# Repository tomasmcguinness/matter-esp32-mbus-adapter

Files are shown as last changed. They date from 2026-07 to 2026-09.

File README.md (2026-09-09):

# Matter ESP32 M-Bus Adapter

> ⚠️ **Work in progress.** This project is under active development and is not
> finished. The hardware is at the bring-up stage, the firmware currently runs in
> a bench-test mode that logs meter data rather than publishing it over Matter,
> and nothing here should be considered stable or production-ready. Expect
> breaking changes, incomplete features and rough edges.

A [Matter](https://csa-iot.org/all-solutions/matter/) accessory that reads a
wired [M-Bus](https://en.wikipedia.org/wiki/Meter-Bus) (EN 13757) heat meter and
exposes its readings — flow rate, flow/return temperatures and power — to a
Matter fabric over Thread.

It is built around an **ESP32-C6** (native 802.15.4 radio) and a custom PCB that
provides the M-Bus master side: the ~36 V/~24 V bus supply, the mark/space
modulator and the receive comparator, so a meter can be connected directly to the
board's M+/M- terminals.

## Repository layout

| Path | Contents |
|---|---|
| `firmware/` | The main ESP-IDF / esp-matter application for the ESP32-C6 |
| `hardware/PCB/` | KiCad schematic, PCB layout and BOM (`PCB.csv`, Mouser part numbers) |
| `tools/pcb-test/` | Standalone GPIO-only app for bringing up the M-Bus analogue circuit — see its own [README](tools/pcb-test/README.md) |

## Firmware

Source lives in `firmware/main`:

- `mbus.cpp` / `mbus.h` — the M-Bus link layer: UART setup (2400 8E1), `SND_NKE`
  link reset and `REQ_UD2` data requests, frame validation and checksums.
- `mbus_parser.cpp` / `mbus_parser.h` — decodes EN 13757-3 data records into a
  `heat_meter_data_t` struct, plus a verbose `mbus_parse_test()` used on the bench.
- `heat_meter_cluster.h` — IDs for a manufacturer-specific *Heat Meter* cluster,
  which carries the meter dataset at higher precision than the standard Flow
  Measurement cluster allows.
- `main.cpp` — brings up the Matter node and endpoints and runs the M-Bus poll task.

### Bring-up modes

`main.cpp` has an `MBUS_MODE` switch so each layer can be proven in turn. It
currently defaults to `MBUS_MODE_TEST`.

| Mode | Behaviour |
|---|---|
| `MBUS_MODE_NKE_ONLY` | Sends `SND_NKE` on a loop and reports whether the meter ACKs — checks wiring and polarity only |
| `MBUS_MODE_TEST` | Requests data and hex-dumps/decodes every record found. Nothing reaches Matter |
| `MBUS_MODE_NORMAL` | Parses into `heat_meter_data_t` and publishes to the Matter data model |

### Building

Requires ESP-IDF (with `esp_matter` pulled in as a managed component — see
`firmware/main/idf_component.yml`).

The radio is chosen by an explicit defaults overlay, so there is no single
`idf.py build` — each variant gets its own build directory and generated config,
and the two never collide. `set-target` is needed once per build directory.

```sh
cd firmware

# Thread — the supported configuration
idf.py -B build.thread -DSDKCONFIG=sdkconfig.thread \
  -DSDKCONFIG_DEFAULTS="sdkconfig.defaults;sdkconfig.defaults.thread" \
  set-target esp32c6
idf.py -B build.thread -DSDKCONFIG=sdkconfig.thread \
  -DSDKCONFIG_DEFAULTS="sdkconfig.defaults;sdkconfig.defaults.thread" \
  build flash monitor

# Wi-Fi — read the warning in sdkconfig.defaults.wifi first
idf.py -B build.wifi -DSDKCONFIG=sdkconfig.wifi \
  -DSDKCONFIG_DEFAULTS="sdkconfig.defaults;sdkconfig.defaults.wifi" \
  set-target esp32c6
idf.py -B build.wifi -DSDKCONFIG=sdkconfig.wifi \
  -DSDKCONFIG_DEFAULTS="sdkconfig.defaults;sdkconfig.defaults.wifi" \
  build flash monitor
```

`SDKCONFIG_DEFAULTS` must be passed to **`set-target` as well as `build`**.
`set-target` is what creates the config file, and defaults are only ever applied
when the file is created — pass it only to `build` and you silently get a config
with no radio overlay at all.

`sdkconfig.defaults.esp32c6` holds the settings common to both and selects no
radio. IDF appends `<file>.esp32c6` to every entry in `SDKCONFIG_DEFAULTS`, so it
is applied automatically and only the radio overlay has to be named.

Note that editing a defaults file does **not** update an existing generated
config — IDF only seeds one that does not yet exist. That is why each variant has
its own `-DSDKCONFIG`; if you do need to re-seed one, delete it first.

BLE is used for commissioning in both cases.

**Wi-Fi does not work on revision F hardware.** The 3V3 LDO (U3, `MCP1700T-3302E/TT`)
supplies 250 mA against a Wi-Fi TX peak north of 300 mA, so the board
brownout-resets at association and never finishes starting. Thread's 802.15.4 TX
peak fits the budget. See `firmware/sdkconfig.defaults.wifi` for the full
measurements and what a hardware fix would need.

### Factory reset

**SW2** is the ESP32-C6 BOOT button (net `BOOT` → IO9). Hold it for **five
seconds while the device is running** to wipe the Matter credentials from NVS and
reboot uncommissioned. The status LED (D3, net `LED` → IO15) blinks faster as the
hold progresses and goes solid at the moment the reset commits, so the button can
be released once it stops flashing.

Release before five seconds and nothing happens — the aborted hold is logged with
its elapsed time.

IO9 is a strapping pin, so holding SW2 *across* a power-up or an SW1 press puts
the chip into serial-download mode and the application never starts. That is
useful for flashing, but it is **not** the factory-reset gesture — the device has
to already be running.

SW1 pulls `EN` low and is a plain hardware reset; it does not touch NVS.

## Known limitations

- Matter publishing is commented out in `main.cpp` while bench testing continues.
- The LDO (U3, `MCP1700`, 250 mA) cannot supply Wi-Fi. Confirmed on the bench:
  10 brownout resets in 15 s, every one at Wi-Fi association. Thread works; Wi-Fi
  needs more bulk capacitance on 3V3 and/or a 500-600 mA regulator.
- The custom cluster uses the Matter **test** vendor ID `0xFFF1`. A real product
  would need an allocated Vendor ID.
- Raw RX hex logging is enabled in `mbus.cpp` (`MBUS_LOG_RAW_RX`) and should be
  turned off for production.
- Only a subset of M-Bus data records is decoded, and it has so far been
  exercised against a test slave rather than a wide range of real meters.

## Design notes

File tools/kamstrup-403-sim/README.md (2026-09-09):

# Kamstrup MULTICAL 403 M-Bus slave simulator

An Arduino sketch that makes a Raspberry Pi Pico answer M-Bus polls the way a
Kamstrup MULTICAL 403 heat meter does, so the ESP32-C6 adapter in `firmware/`
can be exercised without the real meter on the desk.

Unlike the generic bench slave that `mbus_parse_test()` was written for, this
emits a telegram a real 403 would send — Kamstrup identity fields, CI `0x72`
with a proper 12-byte header, and standard EN 13757-3 data records — so it
exercises the **production** decode path, `mbus_parse()`.

Modelled on [HWHardsoft/Arduino-MBUS-Meter](https://github.com/HWHardsoft/Arduino-MBUS-Meter)
(GPLv3, via OpenEnergyMonitor's HeatpumpMonitor), retargeted from its AEG
electricity-meter payload to a heat meter.

## Build

Either RP2040 core works:

- **Arduino Mbed OS RP2040 Boards** — in Boards Manager by default. Serial1's
  pins are fixed at construction, but they are already GP0/GP1.
- **[arduino-pico](https://github.com/earlephilhower/arduino-pico)**
  (earlephilhower) — add the Boards Manager URL
  `https://github.com/earlephilhower/arduino-pico/releases/download/global/package_rp2040_index.json`.
  Lets the sketch move the UART with `setTX`/`setRX`, so `MBUS_TX_PIN` /
  `MBUS_RX_PIN` in `mbusslave.h` can be changed.

The sketch detects which core it is on (`ARDUINO_ARCH_MBED`) and skips the pin
assignment where it is not supported — see `MBUS_SERIAL_PINS_FIXED` in
`mbusslave.h`. The startup banner prints which pins are actually in use. Both
cores honour `SERIAL_8E1`, which is the part M-Bus depends on.

1. Tools → Board → **Raspberry Pi Pico**
2. Open `kamstrup-403-sim.ino`, Upload
3. Serial Monitor at **115200** for the debug console

No libraries to install — the records are hand-rolled, so there is no
`MBUSPayload` dependency.

## Wiring

| Pico | Direction | M-Bus slave HAT |
|---|---|---|
| GP0 (UART0 TX, digital 0) | → | modulator in |
| GP1 (UART0 RX, digital 1) | ← | comparator out |
| GND | — | GND |

The HAT does the level conversion. On the wire, mark/idle is the high bus
voltage (~36 V) and a slave answers by modulating current, never by driving
voltage — see `tools/pcb-test/README.md` for the measured master-side numbers.

Link settings are **2400 baud, 8E1, primary address 0x05**, matching
`firmware/main/mbus.cpp:61-73` and `firmware/main/mbus.h:9`. A mismatch here is
the classic silent failure: the master just times out having received nothing
at all.

## Telegram

```
68 39 39 68
08            C  = RSP_UD
05            A  = primary address
72            CI = variable data, 12-byte header
78 56 34 12   identification 12345678, BCD, LSB first
2D 2C         manufacturer 0x2C2D = "KAM"
34            version
04            medium = heat (volume measured at return)
nn            access number, increments per response
00            status: no alarm, no error
00 00         signature (unused)
-- data records --
04 06 <i32>   Energy                kWh        VIF 0x06 -> 10^3 Wh
04 14 <i32>   Volume                0.01 m3    VIF 0x14 -> 10^-2 m3
04 22 <i32>   On time               hours      VIF 0x22
04 2D <i32>   Power                 0.1 kW     VIF 0x2D -> 10^2 W
04 3B <i32>   Volume flow           l/h        VIF 0x3B -> 10^-3 m3/h
02 59 <i16>   Flow temperature T1   0.01 degC  VIF 0x59 -> 10^-2 degC
02 5D <i16>   Return temperature T2 0.01 degC  VIF 0x5D -> 10^-2 degC
02 61 <i16>   Temperature diff      0.01 K     VIF 0x61 -> 10^-2 K
CS 16
```

`L = 3 + 12 + 42 = 57 (0x39)`, total 63 bytes. `CS` is the plain 8-bit sum of
the 57 bytes from `C` through the last record byte. All data is little-endian.

Every VIF above resolves identically in **both** master decoders — `classify()`
and the bench table `kVifTest[]` in `firmware/main/mbus_parser.cpp` — and the
records consume exactly `L` bytes, which is what `mbus_parse_test()`'s
"clean walk" check requires.

Power is quantised to 0.1 kW by VIF `0x2D`, so a modelled 4.07 kW is reported
as 4.1 kW. That is the real 403 coding, not a rounding bug.

## Golden frame

Printed by `setup()` at `t = 0`, with access number `0x00` (the first real
response carries `0x01`):

```
68 39 39 68 08 05 72 78 56 34 12 2D 2C 34 04 00 00 00 00
04 06 68 10 00 00  04 14 50 46 00 00  04 22 FC 53 00 00
04 2D 29 00 00 00  04 3B BC 02 00 00
02 59 CC 10  02 5D D8 0E  02 61 F4 01
F4 16
```

Decodes as: Kamstrup, medium heat, ID 12345678, energy 4200 kWh, volume
180.00 m³, on time 21500 h, power 4.1 kW, flow 700 l/h, T1 43.00 °C,
T2 38.00 °C, ΔT 5.00 K.

Paste it into an offline decoder (rSCADA `libmbus`, or `wmbusmeters --analyze`)
to check it independently of this repo's parser.

## Simulated values

Flow rate, temperature difference and return temperature are the independent
variables — slow sines on different periods, so the pattern does not look
canned. Everything else is derived from them, the way a real meter's readings
always are:

```
flow     700 +- 250 l/h   (180 s period)
dT         5 +-   2 K     ( 97 s period)
T2        38 +-   3 degC  (240 s period)
T1       = T2 + dT
power    = flow * dT * 1.163 kWh/m3/K
energy  += power * dt      seeded at 4200 kWh
volume  += flow  * dt      seeded at 180 m3
```

Energy and volume accumulate in `double` and only quantise at encode time, so
they rise monotonically. `power_kw` always agrees with `flow * dT * 1.163` — a
master that decodes all three can therefore self-check.

The model advances on a 1 s `millis()` timer independent of polling, so values
move whether or not the master is asking. To swap in fixed values instead, edit
`encode_records()` — nothing else in the sketch knows about scaling.

## Also supported

Beyond SND_NKE / REQ_UD2, the sketch answers the frames a real 403 does:

- **REQ_UD1** — ACK, no class 1 (alarm) data
- **Secondary address selection** (CI `0x52`) — matches on the four BCD ID
  bytes, honouring whole-byte `0xFF` wildcards
- **Change primary address** (CI `0x51`, `01 7A <new>`)
- **Change baud rate** (CI `0xB8`–`0xBD`) — ACKs at the old rate, then switches

Broadcast addresses `0xFD`/`0xFE` are accepted for SND_NKE; a REQ_UD2 on a
broadcast address is answered only after a successful secondary select, so
several slaves on one bus do not all talk at once.

The adapter's master re-sends SND_NKE before every REQ_UD2 and never toggles
the FCB bit (`mbus_request_data()` in `firmware/main/mbus.cpp`), so nothing here
depends on FCB state — but `FCB_BIT_MASK` is applied so a master that does
toggle it still works.

## Verifying against the adapter

```
cd firmware && idf.py -p <port> monitor
```

`MBUS_LOG_RAW_RX` is already `1`, so compare the master's raw RX hex
byte-for-byte against the `tx:` line the Pico prints. Then confirm
`mbus_parse()` — not just `mbus_parse_test()` — resolves all seven quantities,
and that the Matter heat-meter attributes follow.

Left running a few minutes, energy and volume must increase monotonically.
Power-cycling the Pico mid-poll should see the master recover on its next
SND_NKE; a corrupt frame is dropped and the sketch resyncs on the next start
byte rather than wedging.

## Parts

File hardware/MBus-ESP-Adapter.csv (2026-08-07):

Reference | Qty | Mouse_PN
C1 | 1 | 80-C0805C104J4RAUTO
C2 | 1 | 963-MSASL21GBB5226MT
C3,C7 | 2 | 80-C0805C105J4RACLR
C5 | 1 | 80-C0805C105J4RACLR
C6 | 1 | 80-C1206C475K5P
C9 | 1 | 963-MLASU31LBB5106MT
C10 | 1 | 963-MSASU319HB5105KT
D1,D2,D3 | 3 | 630-HSMH-H170
D4 | 1 | 512-SS14
F1 | 1 | 576-1206L050YR
J2 | 1 | 640-USB4105-GF-A
L2 | 1 | 851-CDRH5D18NP-100NC
Q1 | 1 | 583-BC807
Q2,Q3 | 2 | 583-BC817
R3,R4,R6,R7,R8 | 5 | 667-ERA-6ARW512V
R5,R9 | 2 | 603-RT0805BRD0710KL
R10 | 1 | 603-RT0805FRE131ML
R11 | 1 | 603-RT0805FRE0737K4L
R12 | 1 | 603-RT0805BRD0739K2L
R13 | 1 | 603-AT0805BRE0733KL
R14 | 1 | 667-ERA-6AEB224V
R15 | 1 | 603-RT0805BRD0782RL
R16,R17 | 2 | 603-AT0805BRD071KL
R19 | 1 | 603-RT0805DRD0722KL
R20 | 1 | 603-RT0805FRE133K3L
SW1,SW2 | 2 | 640-SWT0110020010SSA
U1 | 1 | 356-ESP32-C6MINI1UH4
U2 | 1 | 621-AP3015AKTR-G1
U3 | 1 | 579-MCP1700T3302E/TT

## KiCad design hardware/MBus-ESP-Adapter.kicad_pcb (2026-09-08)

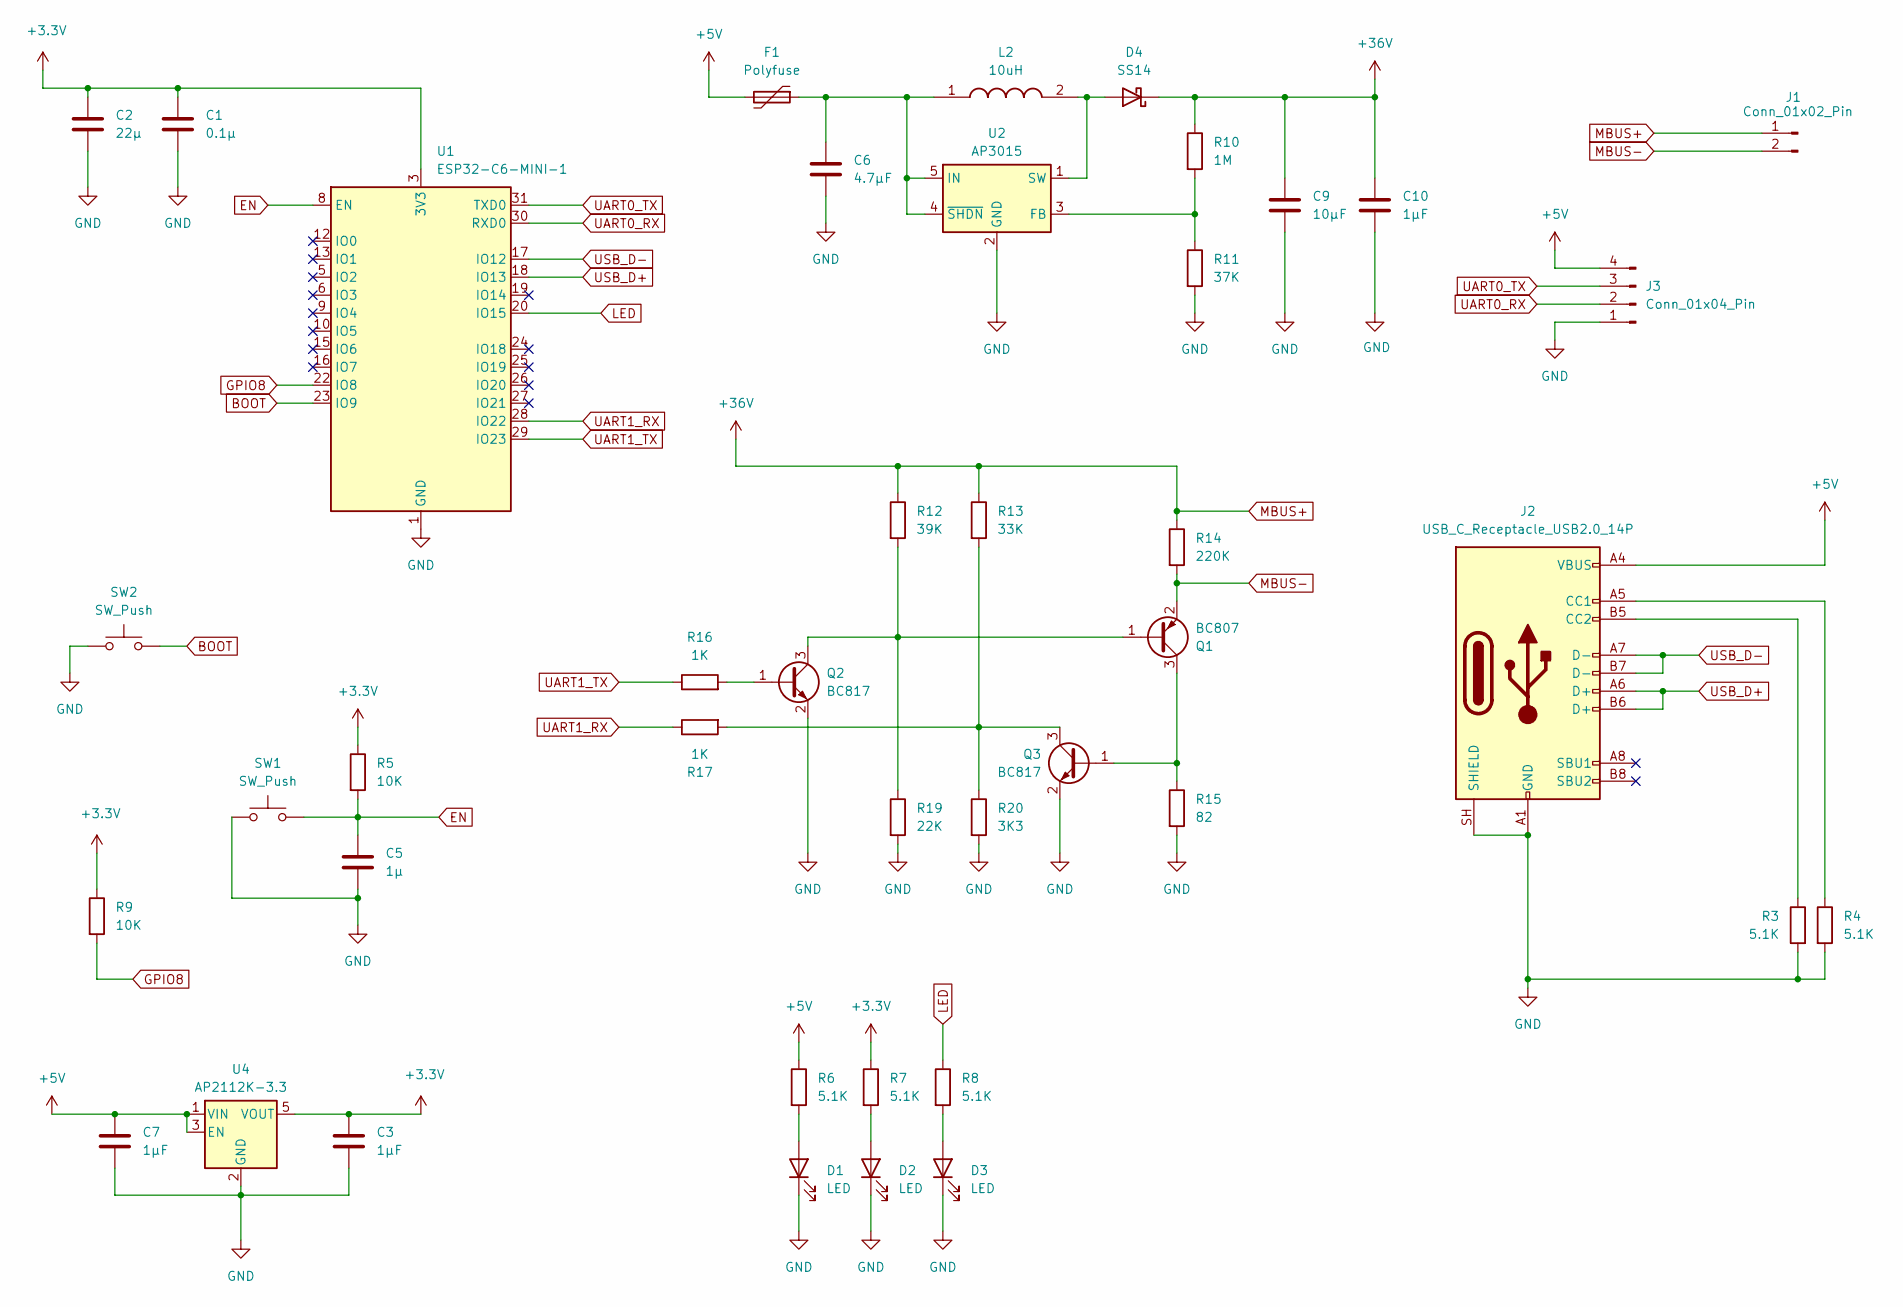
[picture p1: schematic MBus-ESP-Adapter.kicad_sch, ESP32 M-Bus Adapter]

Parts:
C1: 0.1µ; C_0805_2012Metric
C2: 22µ; C_0805_2012Metric
C3, C7: 1µF; C_0805_2012Metric
C5: 1µ; C_0805_2012Metric
C6: 4.7µF; C_1206_3216Metric
C9: 10µF; C_1206_3216Metric
C10: 1µF; C_1206_3216Metric
D1, D2, D3: LED; LED_0805_2012Metric
D4: SS14; D_SMA
F1: Polyfuse; L_1206_3216Metric_Pad1.22x1.90mm_HandSolder
J1: Conn_01x02_Pin; TerminalBlock_MaiXu_MX126-5.0-02P_1x02_P5.00mm
J2: USB_C_Receptacle_USB2.0_14P; USB_C_Receptacle_GCT_USB4105-xx-A_16P_TopMnt_Horizontal
J3: Conn_01x04_Pin; PinHeader_1x04_P2.54mm_Vertical
L2: 10uH; CR54NP221KC; Mouser Part Number 851-CR54NP-100MC
Q1: BC807; SOT-23
Q2, Q3: BC817; SOT-23
R3, R4, R6, R7, R8: 5.1K; R_0805_2012Metric
R5, R9: 10K; R_0805_2012Metric
R10: 1M; R_0805_2012Metric
R11: 37K; R_0805_2012Metric
R12: 39K; R_0805_2012Metric
R13: 33K; R_0805_2012Metric
R14: 220K; R_0805_2012Metric
R15: 82; R_0805_2012Metric
R16, R17: 1K; R_0805_2012Metric
R19: 22K; R_0805_2012Metric
R20: 3K3; R_0805_2012Metric
SW1, SW2: SW_Push; SW_SPST_TS-1088-xR025
U1: ESP32-C6-MINI-1; ESP32-C6-MINI-1U
U2: AP3015; SOT-23-5
U4: AP2112K-3.3; SOT-23-5

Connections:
+3.3V: C1.1, C2.1, C3.1, R5.1, R7.1, R9.1, U1.3 (3V3), U4.5 (VOUT)
+5V: C7.1, F1.2, J2.A4 (VBUS), J2.A9 (VBUS), J2.B4 (VBUS), J2.B9 (VBUS), J3.4, R6.1, U4.1 (VIN), U4.3 (EN)
BOOT: SW2.2, U1.23 (IO9)
EN: C5.1, R5.2, SW1.2, U1.8 (EN)
GND: C1.2, C2.2, C3.2, C5.2, C6.2, C7.2, C9.2, C10.2, D1.1 (K), D2.1 (K), D3.1 (K), J2.A1 (GND), J2.A12 (GND), J2.B1 (GND), J2.B12 (GND), J2.SH (SHIELD), J3.1, Q2.2 (E), Q3.2 (E), R3.2, R4.2, R11.2, R15.2, R19.2, R20.2, SW1.1, SW2.1, U1.1 (GND), U1.2 (GND), U1.11 (GND), U1.14 (GND), U1.36 (GND), U1.37 (GND), U1.38 (GND), U1.39 (GND), U1.40 (GND), U1.41 (GND), U1.42 (GND), U1.43 (GND), U1.44 (GND), U1.45 (GND), U1.46 (GND), U1.47 (GND), U1.48 (GND), U1.49 (GND), U1.50 (GND), U1.51 (GND), U1.52 (GND), U1.53 (GND), U2.2 (GND), U4.2 (GND)
GPIO8: R9.2, U1.22 (IO8)
LED: R8.1, U1.20 (IO15)
MBUS+: C9.1, C10.1, D4.1 (K), J1.1, R10.1, R12.1, R13.1, R14.1
MBUS-: J1.2, Q1.2 (E), R14.2
unnamed: D1.2 (A), R6.2
unnamed: D2.2 (A), R7.2
unnamed: D3.2 (A), R8.2
unnamed: D4.2 (A), L2.2, U2.1 (SW)
unnamed: J2.A5 (CC1), R4.1
unnamed: J2.B5 (CC2), R3.1
unnamed: Q1.1 (B), Q2.3 (C), R12.2, R19.1
unnamed: Q1.3 (C), Q3.1 (B), R15.1
unnamed: Q2.1 (B), R16.2
unnamed: Q3.3 (C), R13.2, R17.2, R20.1
unnamed: R10.2, R11.1, U2.3 (FB)
unnamed: C6.1, F1.1, L2.1, U2.4 (~SHDN), U2.5 (IN)
UART0_RX: J3.2, U1.30 (RXD0)
UART0_TX: J3.3, U1.31 (TXD0)
UART1_RX: R17.1, U1.28 (IO22)
UART1_TX: R16.1, U1.29 (IO23)
USB_D+: J2.A6 (D+), J2.B6 (D+), U1.18 (IO13)
USB_D-: J2.A7 (D-), J2.B7 (D-), U1.17 (IO12)

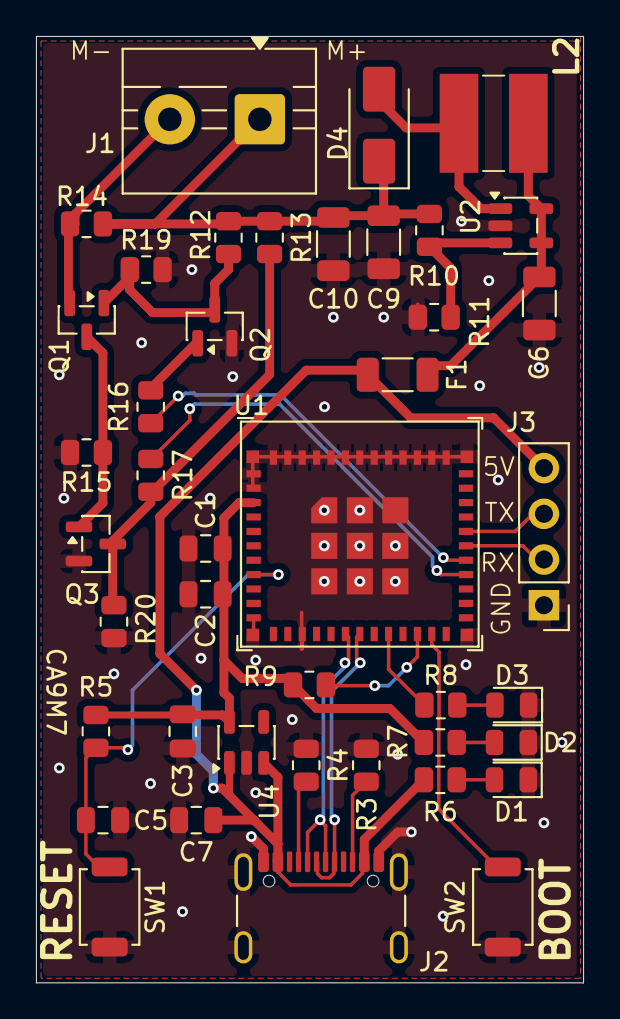
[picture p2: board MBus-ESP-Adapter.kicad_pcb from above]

Board: 2 copper layers, 30.4 x 52.6 mm, 42 parts (0 on the bottom side), 27 nets.

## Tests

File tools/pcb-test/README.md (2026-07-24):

# PCB bring-up test

A tiny standalone ESP-IDF app for testing the M-Bus master circuit on the adapter PCB
*before* trusting UART. It drives GPIO4 (the UART1 TX pin) as a plain GPIO from a serial
console so you can park it at a fixed level and measure M+ / M- with a multimeter, and
reads back GPIO5 (the receiver output).

No Matter, no Thread, no UART driver — just GPIO — so a failure here points squarely at
the hardware.

## Expected voltages

Probe M+ (red) and M- (black), DMM in DC volts:

| GPIO4 (TX) | M+ / M- |
|---|---|
| high (mark / idle) | ~36 V |
| low (space) | ~24 V |

The ~12 V drop is the real result. If the two readings are the same, the modulator isn't
switching. If they're swapped (~24 V idle, ~36 V when low), TX polarity is inverted on
the board — note it, since the real firmware will then need `uart_set_line_inverse()` or
a hardware fix.

## Build and flash

```
cd tools/pcb-test
idf.py set-target esp32c6
idf.py build flash monitor
```

The console appears over the C6's built-in USB Serial/JTAG on the same cable, with a
`pcb>` prompt.

## Commands

| Command | Effect |
|---|---|
| `hi` / `mark` | drive TX high and hold it — expect ~36 V, LED on |
| `lo` / `space` | drive TX low and hold it — expect ~24 V, LED off |
| `sq [ms]` | square wave on TX, default 1000 ms period (50–10000) |
| `stop` | stop the square wave, leave TX idle high |
| `rx` | print GPIO5 level and edge count since boot |
| `status` | TX mode/level plus RX state |
| `help` | list commands |

TX starts high at boot — an M-Bus bus idles at mark, and holding it low looks like a
break condition to some meters.

The LED on GPIO15 mirrors TX: lit = mark (~36 V), dark = space (~24 V), and it blinks
along with `sq`. It gives you a visual confirmation the command landed without looking
away from the multimeter. If your LED is wired active-low (cathode to the pin) it will
read inverted — set `LED_ACTIVE_HIGH` to 0 in `main/main.c`.

## Bring-up order

Stop at the first step that fails.

1. **Supply only.** Power the PCB with the C6 unflashed or held in reset. M+/M- should
   read ~36 V. If not, the boost converter is the fault and no firmware will help.
2. **Flash** this app (above).
3. **Mark.** Type `hi`, probe M+/M-: ~36 V, stable.
4. **Space.** Type `lo`, same points: ~24 V.
5. **Under load.** Repeat 3 and 4 with a 22 kΩ (≥0.1 W) resistor across M+/M- to emulate
   one M-Bus unit load (~1.6 mA at 36 V). The mark voltage should sag only slightly; a
   large sag means the supply can't source bus current, which would later show up as
   unreliable comms.
6. **Toggling.** `sq 1000` and watch the DMM swing, or scope M+ for clean ~12 V steps
   with no ringing or slow edges. `stop` when done.
7. **Receiver path.** Idle bus: `rx` should show a steady level and a static edge count.
   Briefly put a ~1 kΩ resistor across M+/M- (emulating a meter's current-mode reply) and
   run `rx` again — the level should have flipped and/or the edge count moved. That
   confirms the receive comparator reaches GPIO5.

Once 1–7 pass, the analogue side is good and anything still broken is UART framing or the
meter itself — try the main `firmware/` build next (2400 8E1, see
`firmware/main/mbus.cpp`).

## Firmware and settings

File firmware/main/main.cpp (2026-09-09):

#include <esp_err.h>
#include <esp_log.h>
#include <inttypes.h>
#include <esp_matter.h>
#include <nvs_flash.h>

#include <app/server/CommissioningWindowManager.h>
#include <app/server/Server.h>
#include <setup_payload/OnboardingCodesUtil.h>
#include <setup_payload/QRCodeSetupPayloadGenerator.h>

#if CHIP_DEVICE_CONFIG_ENABLE_THREAD
#include <platform/ESP32/OpenthreadLauncher.h>
#include <esp_openthread_types.h>

// The default OpenThread platform config macros are provided by the examples,
// not the SDK. ESP32-C6 has a native 802.15.4 radio (RADIO_MODE_NATIVE).
#define ESP_OPENTHREAD_DEFAULT_RADIO_CONFIG()                                           \
    {                                                                                   \
        .radio_mode = RADIO_MODE_NATIVE,                                                \
    }

#define ESP_OPENTHREAD_DEFAULT_HOST_CONFIG()                                            \
    {                                                                                   \
        .host_connection_mode = HOST_CONNECTION_MODE_NONE,                              \
    }

#define ESP_OPENTHREAD_DEFAULT_PORT_CONFIG()                                            \
    {                                                                                   \
        .storage_partition_name = "nvs", .netif_queue_size = 10, .task_queue_size = 10, \
    }
#endif

#include "freertos/FreeRTOS.h"
#include "freertos/event_groups.h"
#include "freertos/task.h"

#if CHIP_DEVICE_CONFIG_ENABLE_THREAD
#include "esp_ieee802154.h"
#endif

#include "heat_meter_cluster.h"
#include "mbus.h"
#include "mbus_parser.h"
#include "reset_button.h"

#include <math.h>

static const char *TAG = "Main";

using namespace esp_matter;
using namespace esp_matter::attribute;
using namespace esp_matter::cluster;
using namespace esp_matter::endpoint;
using namespace chip::app::Clusters;

static uint16_t flow_endpoint_id = 0;       // standard Flow Measurement (0x0404)
static uint16_t heat_meter_endpoint_id = 0; // custom high-precision cluster

#define MBUS_POLL_INTERVAL_MS 10000

// Matter's Flow Measurement cluster (0x0404) carries MeasuredValue as a uint16
// where MeasuredValue = 10 x flow in m^3/h -- i.e. one count is 0.1 m^3/h, or
// 100 l/h. The meter reports l/h, so this view of the reading loses three
// significant figures; HM_ATTR_FLOW_ID on the custom cluster keeps the accurate
// one. The standard cluster exists so an off-the-shelf controller can read the
// flow at all without knowing anything about the custom cluster.
#define FLOW_MEASUREMENT_PER_M3H 10.0f

// Range advertised by MinMeasuredValue/MaxMeasuredValue, in m^3/h. Sized for a
// residential MULTICAL 403 (qp 1.5, qs 3.0 m^3/h); raise the max for a larger
// meter variant, or readings above it will be clamped.
#define FLOW_SENSOR_MIN_M3H 0.0f
#define FLOW_SENSOR_MAX_M3H 3.0f

// Bring-up mode. Work up the ladder as each layer is proven:
//   NKE_ONLY -> is the bus wired right and does the meter ACK?
//   TEST     -> does a telegram arrive, and what is actually in it?
//   NORMAL   -> parse into heat_meter_data_t and publish to Matter.
#define MBUS_MODE_NORMAL   0
#define MBUS_MODE_NKE_ONLY 1
#define MBUS_MODE_TEST     2

#ifndef MBUS_MODE
#define MBUS_MODE MBUS_MODE_TEST
#endif

#define MBUS_NKE_TEST_INTERVAL_MS 2000
#define MBUS_TEST_INTERVAL_MS 3000

// 802.15.4 transmit power. The C6 will go to +20 dBm, which is far more than a
// domestic Thread mesh needs and more than this board's 3V3 LDO (U3, MCP1700,
// 250 mA) has headroom for -- the board brownout-resets when the radio comes up
// while BLE is still connected. IDF 5.5 exposes no Kconfig for this, so it is
// clamped at runtime. Raise it if the mesh turns out to need the range.
#define THREAD_TX_POWER_DBM 9

// Gate for the M-Bus poll task. Set only while talking to the meter is both
// safe and useful: a fabric exists and no commissioning is in flight. The M-Bus
// master's 36 V boost (U2) is hard-enabled and its input current is drawn from
// the same USB +5V rail as the ESP32's regulator, so polling the meter during
// commissioning piles load onto the supply at exactly the moment the radio
// needs it. There is also nothing to publish to before a fabric exists.
#define APP_EVENT_MBUS_ENABLED BIT0

static EventGroupHandle_t s_app_events;

// Inputs to the gate. Every writer runs on the Matter thread -- app_event_cb or
// a ScheduleLambda -- so they need no locking.
static bool s_commissioned = false;
static bool s_window_open = false;
static bool s_session_in_flight = false;

// Recompute APP_EVENT_MBUS_ENABLED from the three inputs above. Matter thread.
static void update_mbus_gate()
{
    const bool enabled = s_commissioned && !s_window_open && !s_session_in_flight;
    const bool was_enabled = (xEventGroupGetBits(s_app_events) & APP_EVENT_MBUS_ENABLED) != 0;
    if (enabled == was_enabled)
    {
        return;
    }

    if (enabled)
    {
        ESP_LOGI(TAG, "M-Bus polling enabled");
        xEventGroupSetBits(s_app_events, APP_EVENT_MBUS_ENABLED);
    }
    else
    {
        ESP_LOGI(TAG, "M-Bus polling suspended (window=%d session=%d fabric=%d)",
                 s_window_open, s_session_in_flight, s_commissioned);
        xEventGroupClearBits(s_app_events, APP_EVENT_MBUS_ENABLED);
    }
}

#define ABORT_APP_ON_FAILURE(x, ...)               \
    do                                             \
    {                                              \
        if (!(unlikely(x)))                        \
        {                                          \
            __VA_ARGS__;                           \
            vTaskDelay(5000 / portTICK_PERIOD_MS); \
            abort();                               \
        }                                          \
    } while (0)

static void open_commissioning_window_if_necessary()
{
    VerifyOrReturn(chip::Server::GetInstance().GetFabricTable().FabricCount() == 0);

    chip::CommissioningWindowManager &mgr = chip::Server::GetInstance().GetCommissioningWindowManager();
    VerifyOrReturn(mgr.IsCommissioningWindowOpen() == false);

    CHIP_ERROR err = mgr.OpenBasicCommissioningWindow(
        chip::System::Clock::Seconds16(300),
        chip::CommissioningWindowAdvertisement::kDnssdOnly);
    if (err != CHIP_NO_ERROR)
    {
        ESP_LOGE(TAG, "Failed to open commissioning window: %" CHIP_ERROR_FORMAT, err.Format());
    }
}

#if CHIP_DEVICE_CONFIG_ENABLE_THREAD  
static void apply_thread_tx_power()
{
    ESP_LOGI(TAG, "802.15.4 TX power before clamp: %d dBm", esp_ieee802154_get_txpower());

    esp_err_t err = esp_ieee802154_set_txpower(THREAD_TX_POWER_DBM);
    if (err != ESP_OK)
    {
        ESP_LOGW(TAG, "Failed to set 802.15.4 TX power: %s", esp_err_to_name(err));
        return;
    }

    ESP_LOGI(TAG, "802.15.4 TX power now: %d dBm", esp_ieee802154_get_txpower());
}
#endif

static void app_event_cb(const ChipDeviceEvent *event, intptr_t arg)
{
    switch (event->Type)
    {
    case chip::DeviceLayer::DeviceEventType::kCommissioningWindowOpened:
        ESP_LOGI(TAG, "Commissioning window opened");
        s_window_open = true;
        update_mbus_gate();
        break;
    case chip::DeviceLayer::DeviceEventType::kCommissioningWindowClosed:
        // Careful: this also fires the instant PASE is established, with the
        // whole of AddNOC/CASE/CommissioningComplete still to come. Resuming on
        // it alone would put the bus back under load at the worst moment, which
        // is what s_session_in_flight below is for.
        ESP_LOGI(TAG, "Commissioning window closed");
        s_window_open = false;
        update_mbus_gate();
        break;
    case chip::DeviceLayer::DeviceEventType::kCommissioningSessionStarted:
        ESP_LOGI(TAG, "Commissioning session started");
        s_session_in_flight = true;
        update_mbus_gate();
        break;
    case chip::DeviceLayer::DeviceEventType::kCommissioningSessionStopped:
        ESP_LOGI(TAG, "Commissioning session stopped");
        s_session_in_flight = false;
        update_mbus_gate();
        break;
    case chip::DeviceLayer::DeviceEventType::kCommissioningComplete:
        ESP_LOGI(TAG, "Commissioning complete");
        s_commissioned = true;
        s_session_in_flight = false;
        update_mbus_gate();
        break;
    case chip::DeviceLayer::DeviceEventType::kFailSafeTimerExpired:
        // Commissioning gave up part-way. The SDK reopens the window for a
        // retry, so the gate normally stays shut on the window flag alone.
        ESP_LOGW(TAG, "Fail-safe timer expired");
        s_session_in_flight = false;
        update_mbus_gate();
        break;
    case chip::DeviceLayer::DeviceEventType::kFabricRemoved:
        ESP_LOGI(TAG, "Fabric removed");
        s_commissioned = chip::Server::GetInstance().GetFabricTable().FabricCount() > 0;
        update_mbus_gate();
        open_commissioning_window_if_necessary();
        break;
    case chip::DeviceLayer::DeviceEventType::kBLEDeinitialized:
        ESP_LOGI(TAG, "BLE deinitialized");
        break;
    default:
        break;
    }
}

static esp_err_t app_identification_cb(identification::callback_type_t type, uint16_t endpoint_id,
                                       uint8_t effect_id, uint8_t effect_variant, void *priv_data)
{
    return ESP_OK;
}

static esp_err_t app_attribute_update_cb(attribute::callback_type_t type,
                                         uint16_t endpoint_id, uint32_t cluster_id,
                                         uint32_t attribute_id, esp_matter_attr_val_t *val,
                                         void *priv_data)
{
    return ESP_OK;
}

// --- Pushing meter values into the Matter data model -----------------------

// Scale a flow rate in m^3/h to the Flow Measurement cluster's 0.1 m^3/h
// counts, clamped to the range the cluster advertises. A reading outside that
// range means FLOW_SENSOR_MAX_M3H is wrong for the meter on the bus, so say so
// rather than silently reporting a wrong number.
static uint16_t flow_to_measured_value(float flow_m3h)
{
    if (flow_m3h < FLOW_SENSOR_MIN_M3H || flow_m3h > FLOW_SENSOR_MAX_M3H)
    {
        ESP_LOGW(TAG, "flow %.3f m3/h is outside the advertised range %.1f..%.1f -- clamping",
                 flow_m3h, FLOW_SENSOR_MIN_M3H, FLOW_SENSOR_MAX_M3H);
        flow_m3h = (flow_m3h < FLOW_SENSOR_MIN_M3H) ? FLOW_SENSOR_MIN_M3H : FLOW_SENSOR_MAX_M3H;
    }
    return (uint16_t)lroundf(flow_m3h * FLOW_MEASUREMENT_PER_M3H);
}

// Called on the Matter/CHIP thread (via ScheduleLambda) so attribute::update is
// safe to call.
static void publish_meter_data(const heat_meter_data_t &d)
{
    // Flow goes to both endpoints: full precision on the custom cluster, and
    // the standard Flow Measurement cluster for interoperability.
    if (d.has_flow)
    {
        nullable<float> v; v = d.flow_m3h;
        esp_matter_attr_val_t val = esp_matter_nullable_float(v);
        attribute::update(heat_meter_endpoint_id, HEAT_METER_CLUSTER_ID, HM_ATTR_FLOW_ID, &val);

        nullable<uint16_t> mv; mv = flow_to_measured_value(d.flow_m3h);
        esp_matter_attr_val_t mval = esp_matter_nullable_uint16(mv);
        attribute::update(flow_endpoint_id, FlowMeasurement::Id,
                          FlowMeasurement::Attributes::MeasuredValue::Id, &mval);
    }
    else
    {
        // Null is the cluster's "unknown", and the right answer: leaving the
        // last reading in place would have a controller showing a flow rate the
        // meter has stopped reporting.
        esp_matter_attr_val_t mval = esp_matter_nullable_uint16(nullable<uint16_t>());
        attribute::update(flow_endpoint_id, FlowMeasurement::Id,
                          FlowMeasurement::Attributes::MeasuredValue::Id, &mval);
    }
    if (d.has_flow_temp)
    {
        nullable<int32_t> v; v = (int32_t)lround(d.flow_temp_c * 100.0f); // 0.01 degC
        esp_matter_attr_val_t val = esp_matter_nullable_int32(v);
        attribute::update(heat_meter_endpoint_id, HEAT_METER_CLUSTER_ID, HM_ATTR_FLOW_TEMP_ID, &val);
    }
    if (d.has_return_temp)
    {
        nullable<int32_t> v; v = (int32_t)lround(d.return_temp_c * 100.0f); // 0.01 degC
        esp_matter_attr_val_t val = esp_matter_nullable_int32(v);
        attribute::update(heat_meter_endpoint_id, HEAT_METER_CLUSTER_ID, HM_ATTR_RETURN_TEMP_ID, &val);
    }
    if (d.has_power)
    {
        nullable<int64_t> v; v = (int64_t)llround(d.power_w * 1000.0f); // W -> mW
        esp_matter_attr_val_t val = esp_matter_nullable_int64(v);
        attribute::update(heat_meter_endpoint_id, HEAT_METER_CLUSTER_ID, HM_ATTR_POWER_ID, &val);
    }
}

// Block until the gate is open. Called at the top of every poll iteration, so a
// commissioning window opening mid-run parks the bus until commissioning is
// finished rather than only gating the first poll.
static void mbus_wait_until_enabled()
{
    if (xEventGroupGetBits(s_app_events) & APP_EVENT_MBUS_ENABLED)
    {
        return;
    }

    ESP_LOGI(TAG, "M-Bus poll task waiting on the gate");
    xEventGroupWaitBits(s_app_events, APP_EVENT_MBUS_ENABLED, pdFALSE, pdTRUE, portMAX_DELAY);
    ESP_LOGI(TAG, "M-Bus poll task released");
}

static void mbus_poll_task(void *arg)
{
    // Hold off until commissioned and idle -- see APP_EVENT_MBUS_ENABLED.
    mbus_wait_until_enabled();

#if CHIP_DEVICE_CONFIG_ENABLE_THREAD
    // Re-assert after commissioning: if OpenThread pushed its own value while
    // joining, this logs it and puts the clamp back.
    apply_thread_tx_power();
#endif

#if MBUS_MODE == MBUS_MODE_NKE_ONLY

    // Link bring-up: send SND_NKE and report whether the meter ACKs. No data
    // request, no parsing, nothing published to the Matter data model.
    while (true)
    {
        mbus_wait_until_enabled();

        esp_err_t err = mbus_send_nke(MBUS_PRIMARY_ADDRESS);
        ESP_LOGI(TAG, "SND_NKE to 0x%02X -> %s", MBUS_PRIMARY_ADDRESS, esp_err_to_name(err));

        vTaskDelay(pdMS_TO_TICKS(MBUS_NKE_TEST_INTERVAL_MS));
    }

#else

    static uint8_t user[256];

    while (true)
    {
        mbus_wait_until_enabled();

        size_t user_len = 0;
        esp_err_t err = mbus_request_data(MBUS_PRIMARY_ADDRESS, user, sizeof(user), &user_len);
        if (err == ESP_OK)
        {
#if MBUS_MODE == MBUS_MODE_TEST
            // Bench mode: dump the user block and log every data record we can
            // decode, whatever quantity it is. Nothing reaches Matter.
            ESP_LOG_BUFFER_HEXDUMP(TAG, user, user_len, ESP_LOG_INFO);
            mbus_parse_test(user, user_len);
#else
            heat_meter_data_t data;
            if (mbus_parse(user, user_len, &data) == ESP_OK)
            {
                ESP_LOGI(TAG,
                         "flow=%.3f m3/h energy=%.0f Wh volume=%.4f m3 Tflow=%.2f Tret=%.2f power=%.1f W",
                         data.has_flow ? data.flow_m3h : NAN,
                         data.has_energy ? data.energy_wh : NAN,
                         data.has_volume ? data.volume_m3 : NAN,
                         data.has_flow_temp ? data.flow_temp_c : NAN,
                         data.has_return_temp ? data.return_temp_c : NAN,
                         data.has_power ? data.power_w : NAN);

                // ScheduleLambda only stores a small closure (<= 24 bytes), so
                // pass the snapshot by heap pointer, not by value.
                heat_meter_data_t *snapshot = new heat_meter_data_t(data);
                chip::DeviceLayer::SystemLayer().ScheduleLambda([snapshot]() {
                    publish_meter_data(*snapshot);
                    delete snapshot;
                });
            }
            else
            {
                ESP_LOGW(TAG, "Failed to parse M-Bus telegram");
            }
#endif
        }
        else
        {
            ESP_LOGW(TAG, "REQ_UD2 failed: %s", esp_err_to_name(err));
        }

#if MBUS_MODE == MBUS_MODE_TEST
        vTaskDelay(pdMS_TO_TICKS(MBUS_TEST_INTERVAL_MS));
#else
        vTaskDelay(pdMS_TO_TICKS(MBUS_POLL_INTERVAL_MS));
#endif
    }

#endif // MBUS_MODE
}

// --- Custom cluster construction -------------------------------------------
static void create_heat_meter_endpoint(node_t *node)
{
    endpoint_t *ep = endpoint::create(node, ENDPOINT_FLAG_NONE, NULL);
    ABORT_APP_ON_FAILURE(ep != nullptr, ESP_LOGE(TAG, "Failed to create heat meter endpoint"));

    // Descriptor (0x001D) is mandatory on every endpoint, and its DeviceTypeList
    // attribute is the only thing that tells a controller what device type the
    // endpoint is. add_device_type() below only records the id in esp-matter's
    // own endpoint struct -- the Descriptor server is what publishes it.
    //
    // The device-type helpers (flow_sensor::create and the rest) get this for
    // free because they go through common::create(), which creates the
    // descriptor cluster first. endpoint::create() is the raw call and does not,
    // so a custom endpoint has to add it by hand.
    cluster::descriptor::config_t descriptor_config;
    cluster_t *descriptor = cluster::descriptor::create(ep, &descriptor_config, CLUSTER_FLAG_SERVER);
    ABORT_APP_ON_FAILURE(descriptor != nullptr, ESP_LOGE(TAG, "Failed to create descriptor cluster"));

    esp_err_t dt_err = endpoint::add_device_type(ep, HEAT_METER_DEVICE_TYPE_ID, HEAT_METER_DEVICE_TYPE_VER);
    ABORT_APP_ON_FAILURE(dt_err == ESP_OK, ESP_LOGE(TAG, "Failed to add heat meter device type"));

    cluster_t *hm = cluster::create(ep, HEAT_METER_CLUSTER_ID, CLUSTER_FLAG_SERVER);
    ABORT_APP_ON_FAILURE(hm != nullptr, ESP_LOGE(TAG, "Failed to create heat meter cluster"));

    uint16_t flags = ATTRIBUTE_FLAG_NULLABLE;
    attribute::create(hm, HM_ATTR_FLOW_ID, flags, esp_matter_nullable_float(nullable<float>()));
    attribute::create(hm, HM_ATTR_FLOW_TEMP_ID, flags, esp_matter_nullable_int32(nullable<int32_t>()));
    attribute::create(hm, HM_ATTR_RETURN_TEMP_ID, flags, esp_matter_nullable_int32(nullable<int32_t>()));
    attribute::create(hm, HM_ATTR_POWER_ID, flags, esp_matter_nullable_int64(nullable<int64_t>()));

    heat_meter_endpoint_id = endpoint::get_id(ep);
    ESP_LOGI(TAG, "Heat meter endpoint created: id %d", heat_meter_endpoint_id);
}
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
extern "C" void app_main()
{
    nvs_flash_init();

    // Must exist before esp_matter::start(), which can deliver events, and
    // before the poll task is created.
    s_app_events = xEventGroupCreate();
    ABORT_APP_ON_FAILURE(s_app_events != nullptr, ESP_LOGE(TAG, "Failed to create event group"));

    mbus_uart_init();
    ESP_LOGI(TAG, "M-Bus UART initialized");

    // Root node (endpoint 0)
    node::config_t node_config;
    node_t *node = node::create(&node_config, app_attribute_update_cb, app_identification_cb);
    ABORT_APP_ON_FAILURE(node != nullptr, ESP_LOGE(TAG, "Failed to create Matter node"));

    // Custom heat meter cluster.
    create_heat_meter_endpoint(node);

    // Standard Flow Measurement. Created after the heat meter endpoint on
    // purpose: endpoint ids are handed out in creation order, so adding this
    // first would shift the heat meter endpoint and break controllers that are
    // already commissioned against it.
    create_flow_sensor_endpoint(node);

#if CHIP_DEVICE_CONFIG_ENABLE_THREAD
    /* Set OpenThread platform config */
    esp_openthread_platform_config_t config = {
        .radio_config = ESP_OPENTHREAD_DEFAULT_RADIO_CONFIG(),
        .host_config = ESP_OPENTHREAD_DEFAULT_HOST_CONFIG(),
        .port_config = ESP_OPENTHREAD_DEFAULT_PORT_CONFIG(),
    };
    set_openthread_platform_config(&config);
#endif

    esp_err_t err = esp_matter::start(app_event_cb);
    ABORT_APP_ON_FAILURE(err == ESP_OK, ESP_LOGE(TAG, "Failed to start Matter, err:%d", err));

    // Not fatal: a dead button should not stop the meter from being read.
    err = reset_button_init();
    if (err != ESP_OK)
    {
        ESP_LOGE(TAG, "Failed to init reset button: %s", esp_err_to_name(err));
    }

#if CHIP_DEVICE_CONFIG_ENABLE_THREAD
    apply_thread_tx_power();
#endif

    // A node that is already commissioned gets no kCommissioningComplete on a
    // reboot, so seed the gate from the live state here instead. The window may
    // already have been opened by esp_matter::start() -- re-reading it rather
    // than assuming closed covers a re-commissioning of a node that still holds
    // an older fabric. Run on the Matter thread because it owns both objects.
    chip::DeviceLayer::SystemLayer().ScheduleLambda([]() {
        s_commissioned = chip::Server::GetInstance().GetFabricTable().FabricCount() > 0;
        s_window_open = chip::Server::GetInstance().GetCommissioningWindowManager().IsCommissioningWindowOpen();
        ESP_LOGI(TAG, "Startup gate: fabric=%d window=%d", s_commissioned, s_window_open);
        update_mbus_gate();
    });

    xTaskCreate(mbus_poll_task, "mbus_poll", 4096, NULL, 5, NULL);
}

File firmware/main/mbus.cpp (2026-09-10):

#include "mbus.h"

#include "driver/uart.h"
#include "driver/gpio.h"
#include "esp_log.h"
#include "freertos/FreeRTOS.h"
#include "freertos/task.h"
#include "freertos/queue.h"

#include <string.h>

// --- Wiring / UART configuration -------------------------------------------
// The DYBKRADIO adapter does the M-Bus <-> TTL level conversion, so the ESP32
// just drives a plain UART. M-Bus uses 2400 baud, 8 data bits, EVEN parity,
// 1 stop bit. Pins below avoid the C6 strapping/USB-JTAG pins.
#define MBUS_UART   UART_NUM_1
#define MBUS_TXD_PIN ((gpio_num_t)23)  // ESP TX -> adapter RX
#define MBUS_RXD_PIN ((gpio_num_t)22)  // ESP RX <- adapter TX

// M-Bus frame markers / control fields (EN 13757-2)
#define MBUS_START_SHORT 0x10
#define MBUS_START_LONG  0x68
#define MBUS_STOP        0x16
#define MBUS_C_SND_NKE   0x40  // link reset
#define MBUS_C_REQ_UD2   0x5B  // request user data (class 2), FCB=0
#define MBUS_ACK         0xE5  // single-byte acknowledge

#define MBUS_RX_BUF_SIZE 512
#define MBUS_EVENT_QUEUE_LEN 32

// Timeouts. uart_read_bytes() does NOT decrement its ticks_to_wait between
// ring-buffer chunks (esp_driver_uart/src/uart.c), so one call bounds the gap
// between chunks, never the whole read. Treat it as a character-gap timer and
// do the framing here.
#define MBUS_RESP_TIMEOUT_MS 1500  // silence after REQ_UD2 before we give up
#define MBUS_CHAR_TIMEOUT_MS  250  // gap between characters *within* a frame.
                                   // One byte at 2400 8E1 is 4.6 ms and EN
                                   // 13757-2 allows 11 bit times between
                                   // characters, so this is ~50x generous -
                                   // but short enough that a slave that dies
                                   // mid-telegram is reported as a stall
                                   // rather than as a mystery short read.

// Hex-dump the whole RX burst before any framing checks. Without this every
// early return below (bad L/L, missing stop byte, checksum mismatch) throws
// away the only evidence of what the meter actually sent. Set to 0 in
// production.
#define MBUS_LOG_RAW_RX 1

static const char *TAG = "MBus";

// UART event queue. Installed purely for diagnosis: it is the only way to see
// the hardware's framing and parity verdicts, and on this bus those are the
// tell for a character that arrived with its bits distorted rather than one
// that was never sent. The RX data is unaffected either way - esp_driver_uart
// resets the RX FIFO only on overflow and in RS485 modes, never on a framing or
// parity error - so nothing here changes what mbus_read_exact() sees.
static QueueHandle_t s_uart_events = NULL;

typedef struct {
    int framing;
    int parity;
    int overflow;
    int brk;
} mbus_uart_errs_t;

// Drain the event queue, tallying into `out` when given. uart_flush_input()
// does NOT clear this queue, so it has to be drained explicitly before a poll
// or the previous telegram's errors are still sitting in it.
static void mbus_collect_uart_errors(mbus_uart_errs_t *out)
{
    if (s_uart_events == NULL) {
        return;
    }
    uart_event_t ev;
    while (xQueueReceive(s_uart_events, &ev, 0) == pdTRUE) {
        if (out == NULL) {
            continue;
        }
        switch (ev.type) {
        case UART_FRAME_ERR:  out->framing++;  break;
        case UART_PARITY_ERR: out->parity++;   break;
        case UART_FIFO_OVF:   out->overflow++; break;
        case UART_BREAK:      out->brk++;      break;
        default:                               break;
        }
    }
}

static uint8_t mbus_checksum(const uint8_t *data, size_t len)
{
    uint8_t cs = 0;
    for (size_t i = 0; i < len; i++) {
        cs = (uint8_t)(cs + data[i]);
    }
    return cs;
}

// Read exactly `want` bytes, tolerating the burst arriving in chunks.
// Returns the number actually read; < want means `timeout_ms` elapsed with the
// bus idle.
static int mbus_read_exact(uint8_t *dst, int want, int timeout_ms)
{
    int got = 0;
    while (got < want) {
        int n = uart_read_bytes(MBUS_UART, dst + got, want - got, pdMS_TO_TICKS(timeout_ms));
        if (n <= 0) {
            break;
        }
        got += n;
    }
    return got;
}

static void mbus_send_short_frame(uint8_t c, uint8_t addr)
{
    uint8_t frame[5];
    frame[0] = MBUS_START_SHORT;
    frame[1] = c;
    frame[2] = addr;
    frame[3] = (uint8_t)(c + addr); // checksum over C + A
    frame[4] = MBUS_STOP;

    uart_write_bytes(MBUS_UART, (const char *)frame, sizeof(frame));
    uart_wait_tx_done(MBUS_UART, pdMS_TO_TICKS(100));
}

void mbus_uart_init(void)
{
    uart_config_t uart_config = {
        .baud_rate = 2400,
        .data_bits = UART_DATA_8_BITS,
        .parity = UART_PARITY_EVEN,
        .stop_bits = UART_STOP_BITS_1,
        .flow_ctrl = UART_HW_FLOWCTRL_DISABLE,
        .source_clk = UART_SCLK_DEFAULT,
    };

    uart_param_config(MBUS_UART, &uart_config);
    uart_set_pin(MBUS_UART, MBUS_TXD_PIN, MBUS_RXD_PIN, UART_PIN_NO_CHANGE, UART_PIN_NO_CHANGE);
    uart_driver_install(MBUS_UART, MBUS_RX_BUF_SIZE, 0,
                        MBUS_EVENT_QUEUE_LEN, &s_uart_events, 0);
}

esp_err_t mbus_send_nke(uint8_t primary_addr)
{
    uart_flush_input(MBUS_UART);

    ESP_LOGI(TAG, "TX SND_NKE: 10 %02X %02X %02X 16", MBUS_C_SND_NKE, primary_addr,
             (uint8_t)(MBUS_C_SND_NKE + primary_addr));
    mbus_send_short_frame(MBUS_C_SND_NKE, primary_addr);

    // A slave that accepts the reset answers with a single 0xE5 within the
    // 11-330 bit-time window; 1 s is generous at 2400 baud.
    uint8_t rx[16];
    int len = uart_read_bytes(MBUS_UART, rx, sizeof(rx), pdMS_TO_TICKS(1000));
    if (len <= 0) {
        ESP_LOGW(TAG, "No ACK from meter at 0x%02X", primary_addr);
        return ESP_ERR_TIMEOUT;
    }

    ESP_LOG_BUFFER_HEX_LEVEL(TAG, rx, len, ESP_LOG_INFO);

    for (int i = 0; i < len; i++) {
        if (rx[i] == MBUS_ACK) {
            ESP_LOGI(TAG, "ACK (0xE5) received from meter at 0x%02X", primary_addr);
            return ESP_OK;
        }
    }

    ESP_LOGW(TAG, "Got %d byte(s) but no ACK (0xE5)", len);
    return ESP_ERR_INVALID_RESPONSE;
}
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

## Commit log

2026-07-01 Initial project
    [partitions.csv]
2026-07-01 WIP on PCB design
    [PCB.kicad_pcb, PCB.kicad_sch]
2026-07-02 Finished initial schematic and PCB
    [PCB.csv, PCB.kicad_pcb, PCB.kicad_sch]
2026-07-03 WIP - Adding BOM
    [PCB.kicad_sch]
2026-07-03 Finish BOMed and made some pad size adjustments for higher voltage tracks
    [PCB.kicad_pcb, PCB.kicad_sch]
2026-07-03 Add debugging header
    [PCB.kicad_pcb, PCB.kicad_sch]
2026-07-07 Add name and revision details to PCB
    [PCB.kicad_pcb]
2026-07-08 Simplify the Heat Meter device
2026-07-10 Update BOM to correct C9
    [PCB.csv, PCB.kicad_pcb, PCB.kicad_sch]
2026-07-10 Slight tweak as previous component was out of stock
    [PCB.kicad_sch]
2026-07-10 Tweak for out of stock component.
    [PCB.csv]
2026-07-11 WIP First pass through revision C
    [PCB.kicad_pcb, PCB.kicad_sch]
2026-07-11 WIP Revision C
    [PCB.kicad_pcb]
2026-07-13 WIP track sizes
    [PCB.kicad_pcb]
2026-07-14 More tweaks to revision C
    [PCB.kicad_pcb, PCB.kicad_sch]
2026-07-16 Added Front GND pour.
    [PCB.kicad_pcb, PCB.kicad_sch]
2026-07-21 Revision E!
    Moved the two decoupling capacitors
    [PCB.kicad_pcb]
2026-07-23 Revision F appears done.
    I moved the capacitors and inductor positions.
    [PCB.kicad_pcb, PCB.kicad_sch]
2026-07-23 Another few tweaks to tighten voltage booster components. Swapped debug header to remove long 5V trace
    [PCB.kicad_pcb, PCB.kicad_sch]
2026-07-23 More tweaks to revision F
    [PCB.kicad_pcb]
2026-07-24 Small part number tweaks.
    [PCB.csv, PCB.kicad_pcb, PCB.kicad_sch]
2026-08-03 Rename the files
    [MBus-ESP-Adapter.csv, MBus-ESP-Adapter.kicad_pcb, MBus-ESP-Adapter.kicad_sch]
2026-08-07 Add code to read test data from Slave HAT on Pico
2026-09-02 Ignore schematic lock
2026-09-02 Start of Revision G
    [MBus-ESP-Adapter.kicad_pcb, MBus-ESP-Adapter.kicad_sch]
2026-09-02 Revision G tweaks
    [MBus-ESP-Adapter.kicad_pcb, MBus-ESP-Adapter.kicad_sch]
2026-09-02 Revision G update
    [MBus-ESP-Adapter.kicad_pcb]
2026-09-09 Updated to allow for WiFi and Thread network selection. Add custom Heat Meter device type and cluster.
2026-09-10 Change MBus device address
2026-09-12 Update MBus frame parsing to pull out instananeous values.
2026-09-12 Switch from m3/h to L/h as sent by the meter. Logging added for network disconnect.
2026-10-22 Fix Matter vendor/product name showing as TEST_VENDOR/TEST_PRODUCT (#6)
    BasicInformation is a ServerClusterInterface-backed cluster in the
    connectedhomeip version bundled with esp_matter 1.6, same as
    FlowMeasurement: it reads VendorName/ProductName from the compile-time
    CHIP_DEVICE_CONFIG_DEVICE_VENDOR_NAME/PRODUCT_NAME macros via the
    transitional DeviceInstanceInfoProvider, not from esp-matter's own
    attribute store, so the project's config never reached it and
    controllers (Apple Home, etc.) showed the upstream defaults
    "TEST_VENDOR"/"TEST_PRODUCT".
    Add main/CHIPProjectConfig.h to override both macros, and wire
    CHIP_DEVICE_PROJECT_CONFIG_INCLUDE plus main/'s include path in
    project to the w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
